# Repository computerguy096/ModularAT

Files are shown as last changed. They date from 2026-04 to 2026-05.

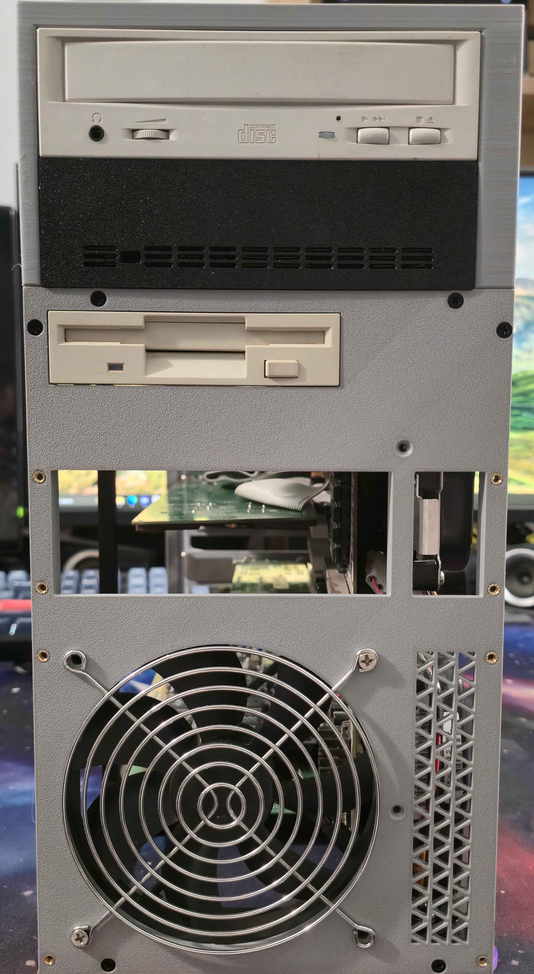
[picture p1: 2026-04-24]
images/front.jpg

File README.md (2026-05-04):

# ModularAT

A fully 3D printable computer case for Baby AT shaped motherboards, with new features the originals never had.

- modular design, can be assembled in a much smaller version
- compatible with all Baby AT motherboards (up to 330mm deep in the full configuration)
- customizable rear I/O area: supports motherboards with AT + PS/2 mouse combo, dual PS/2, etc
- 120mm intake fan: silent operation with plenty of airflow
- three hard drive mount points
- two 5.25 inch (half height, full length) drive bays
- one 3.5 inch drive bay for floppy drives
- ATX power supply support
- improved cable management, with dedicated space behind the motherboard tray for cables
- does not use those pesky plastic pegs!

The assembly instructions can be found at [this link](documentation/user_manual.pdf).

It is currently under development so it is possible some parts might not be finalized, print at your own risk.
main

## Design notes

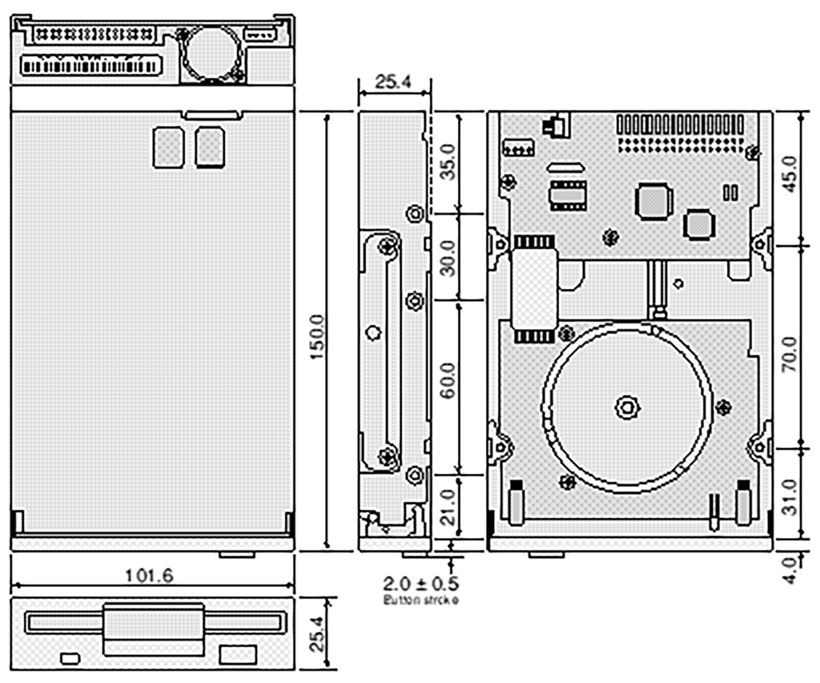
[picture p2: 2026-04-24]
documentation/floppy_spec.jpg

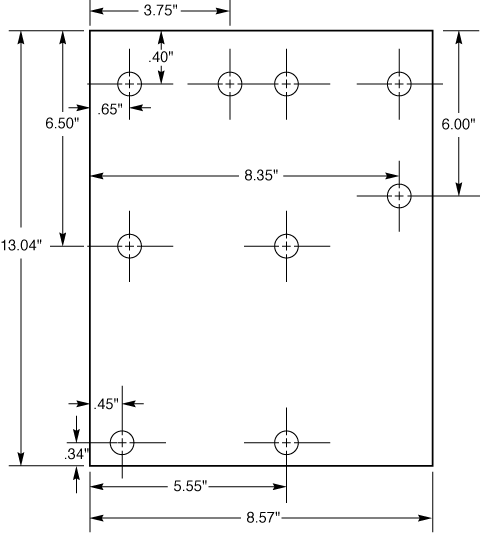
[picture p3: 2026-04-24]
documentation/babyAT_spec.gif

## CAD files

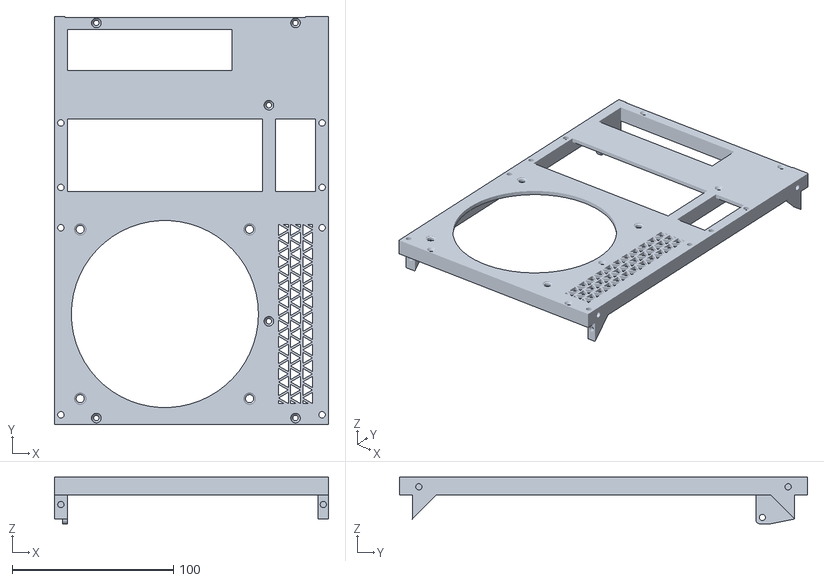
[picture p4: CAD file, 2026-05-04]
STL/frame/Front panel - main.stl
170.0 x 253.0 x 29.0

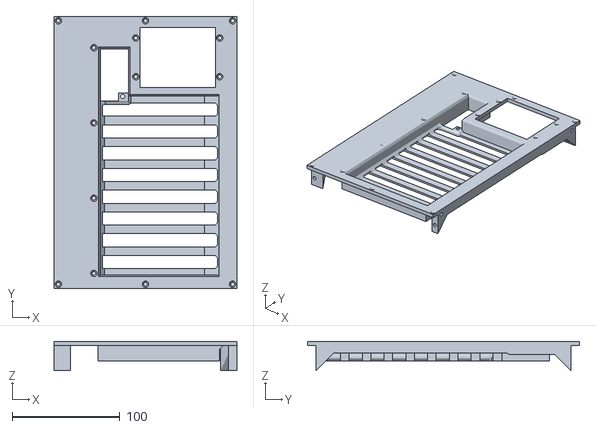
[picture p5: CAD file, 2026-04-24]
STL/frame/Rear panel - main.stl
170.0 x 253.0 x 27.1

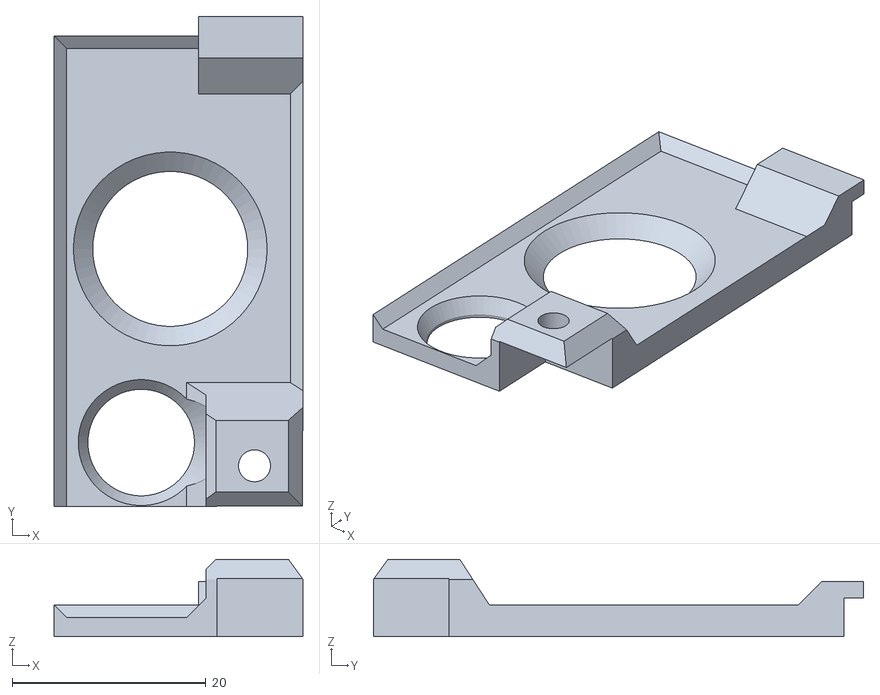
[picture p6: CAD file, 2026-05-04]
STL/accessories/KB cover - ATPS2.stl
25.7 x 50.6 x 8.00

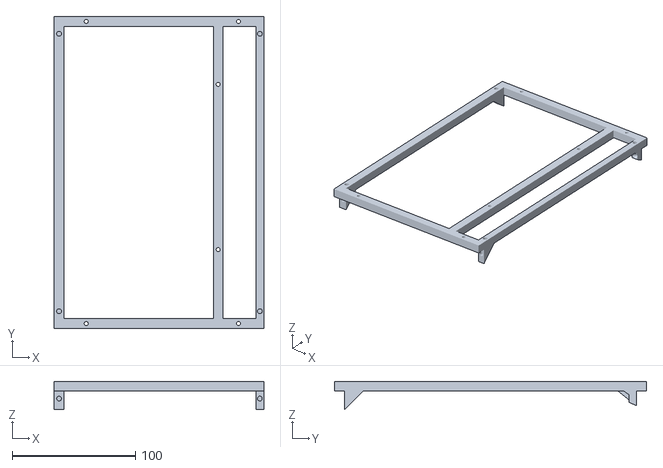
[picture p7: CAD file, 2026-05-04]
STL/frame/Stability frame.stl
170.0 x 253.0 x 23.0

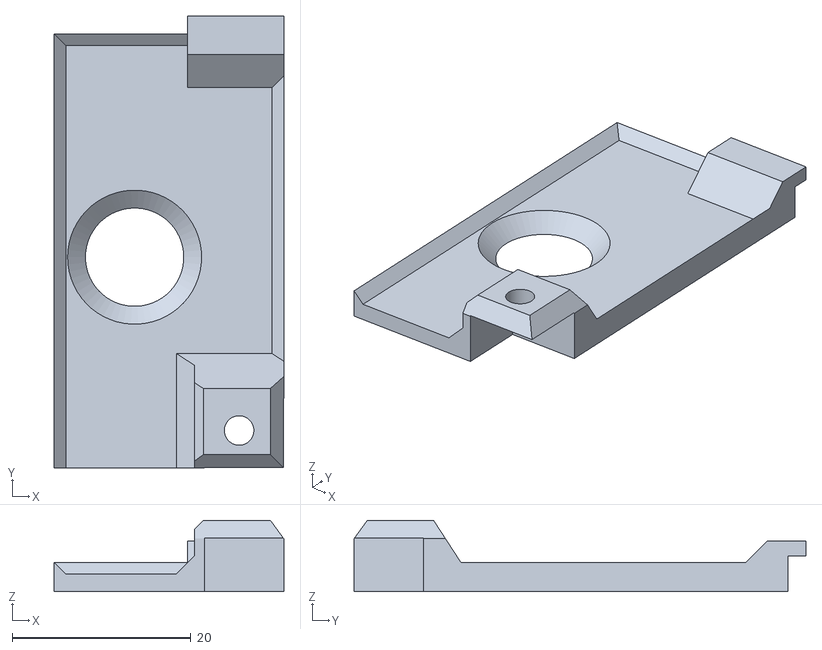
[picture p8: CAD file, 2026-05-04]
STL/accessories/KB cover - PS2.stl
25.7 x 50.6 x 8.00

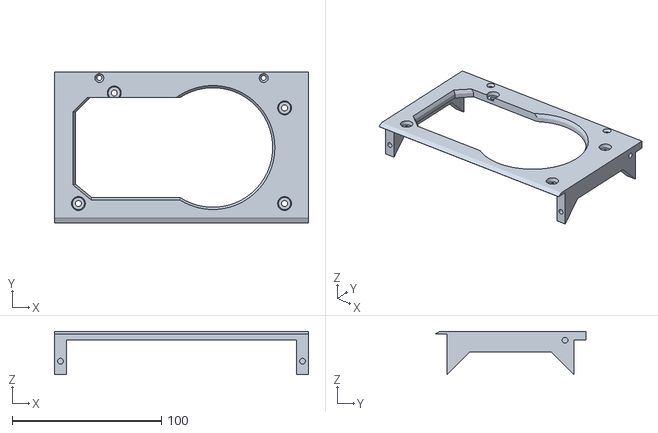
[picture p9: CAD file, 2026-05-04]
STL/frame/Rear panel - PSU plate.stl
170.0 x 101.0 x 29.1

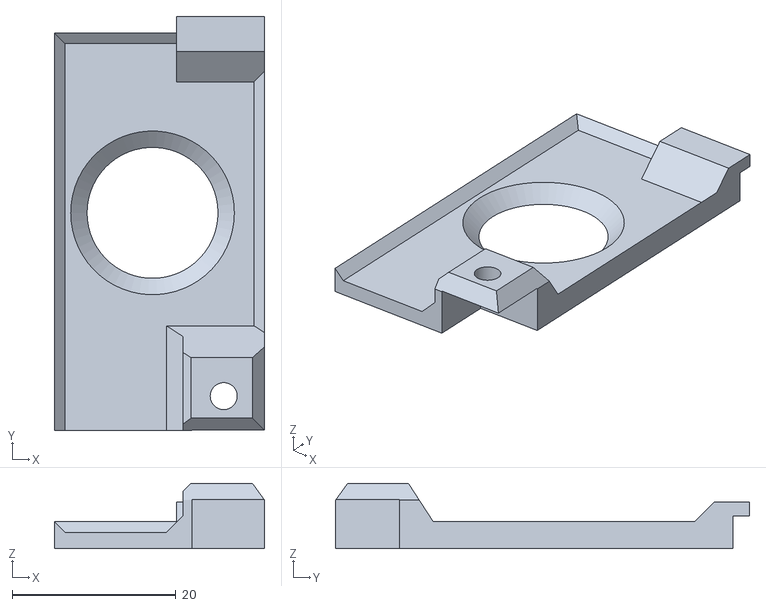
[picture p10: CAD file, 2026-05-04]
STL/accessories/KB cover- AT.stl
25.7 x 50.6 x 8.00

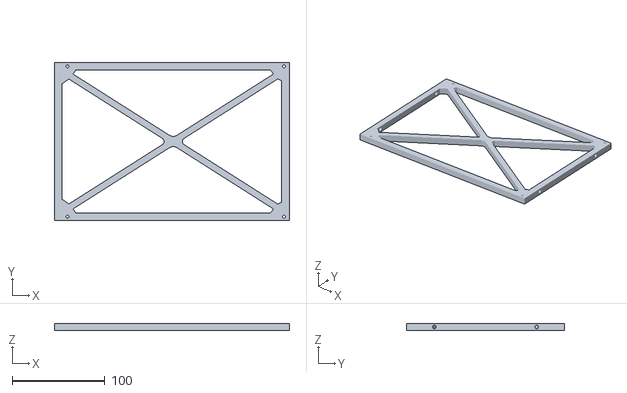
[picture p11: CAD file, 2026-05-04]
STL/frame/Top frame.stl
253.0 x 170.0 x 8.00

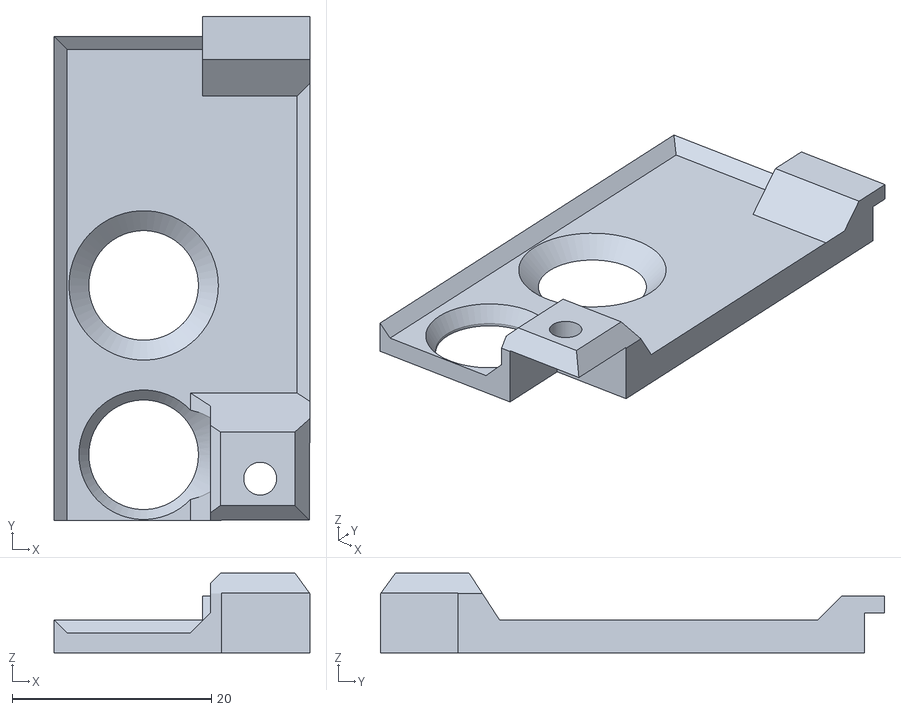
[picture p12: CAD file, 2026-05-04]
STL/accessories/KB cover - dual PS2.stl
25.7 x 50.6 x 8.00

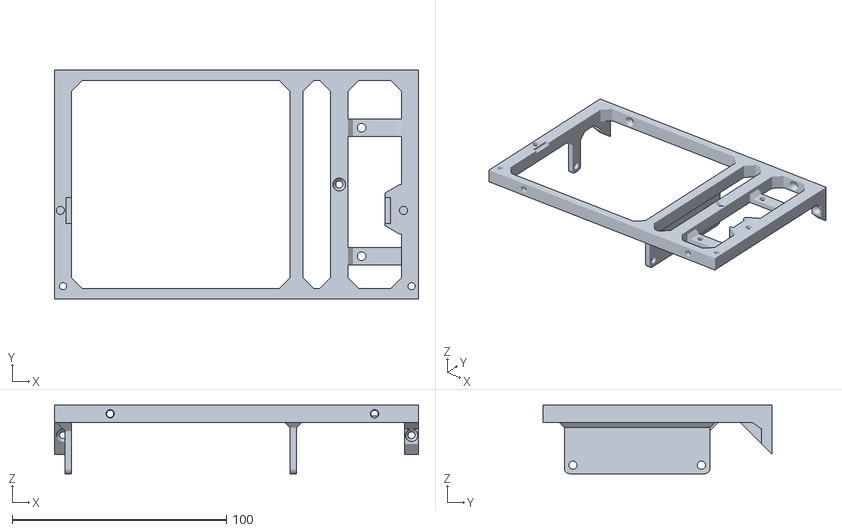
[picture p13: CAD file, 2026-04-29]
STL/frame/Middle extension frame.stl
170.0 x 107.0 x 32.0

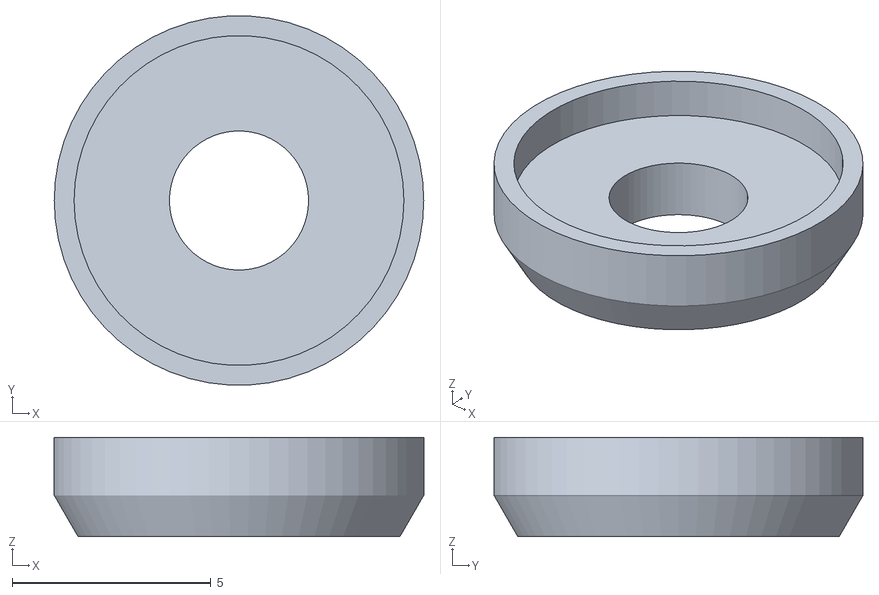
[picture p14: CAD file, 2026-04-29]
STL/accessories/Motherboard spacer.stl
9.30 x 9.29 x 2.50

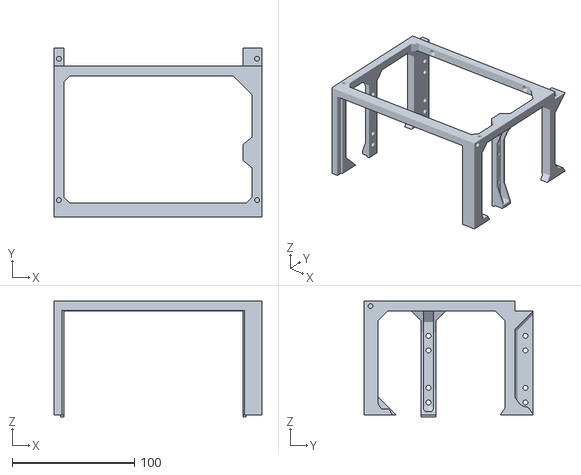
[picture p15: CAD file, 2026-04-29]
STL/frame/Top extension frame.stl
170.0 x 138.5 x 94.5

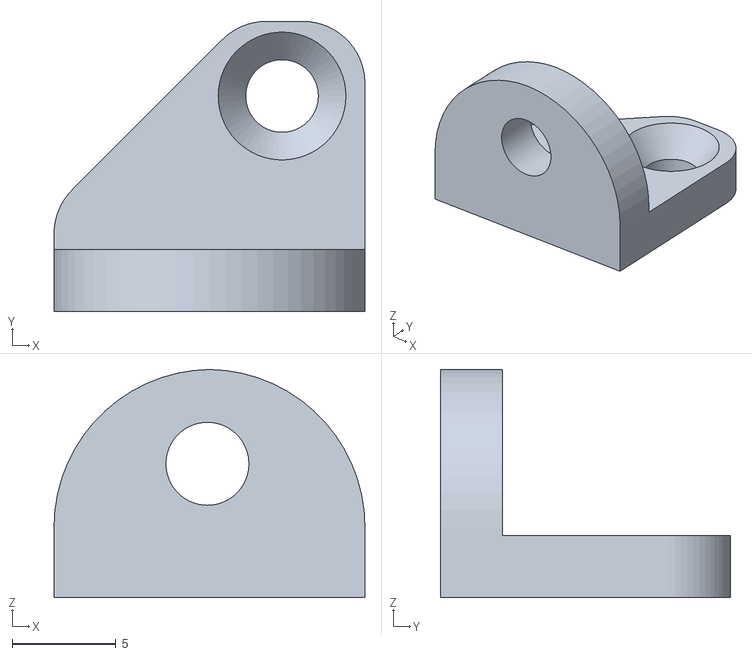
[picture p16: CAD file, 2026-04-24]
STL/accessories/HDD holder front upper.stl
15.0 x 14.0 x 11.0

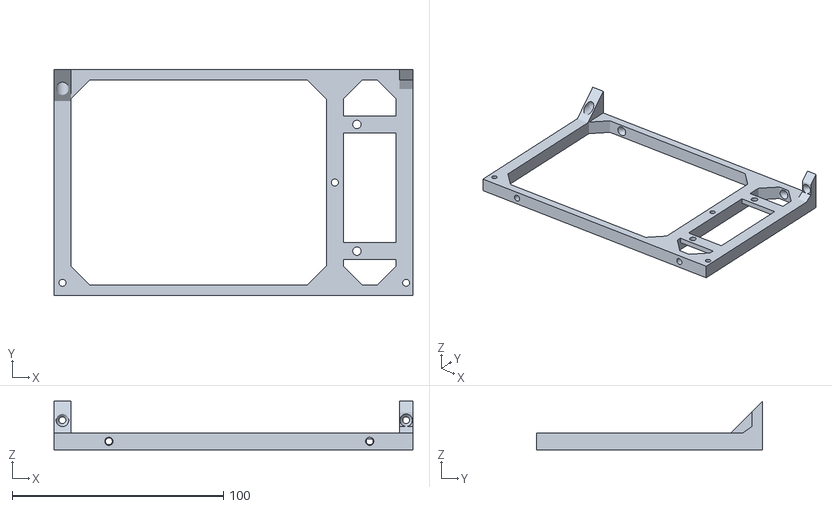
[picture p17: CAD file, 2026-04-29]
STL/frame/Bottom extension frame.stl
170.0 x 107.0 x 23.0

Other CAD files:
STL/accessories/KB cover - dual PS2 offset.stl
STL/accessories/HDD holder rear.stl
STL/frame/Bottom frame.stl
STL/accessories/HDD holder front lower.stl
STL/accessories/KB cover - blank.stl
STL/frame/Base extension frame.stl
STL/frame/Base frame.stl
STL/frame/Middle frame.stl

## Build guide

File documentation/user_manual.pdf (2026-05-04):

# ModularAT

## User’s guide

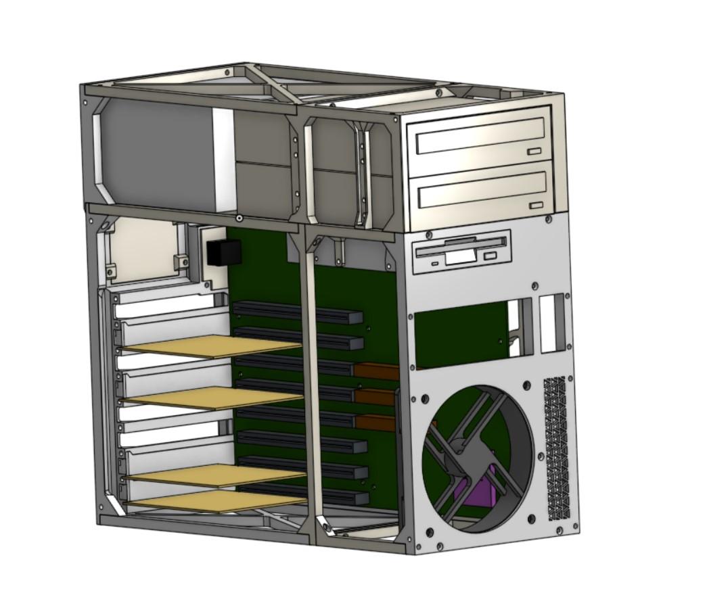
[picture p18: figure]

Revision 0.9-preliminary
May 4th, 2026

# Table of contents

A. Introduction | 3
1. What does this fit? | 3
2. Parts compatibility | 4
3. Brass inserts | 4
B. Bill of materials | 5
C. Getting started | 5
1. Base frame | 6
2. Rear frame | 7
3. Bottom frame | 8
4. Middle frame | 8
5. Stability frame | 9
6. Bottom extension frame | 10
7. Middle extension frame | 10
8. Base extension frame | 11
9. Front frame | 12
10. PSU frame | 13
11. Top frame | 13
12. Top extension frame | 14
D. Assembly | 15

## A. Introduction

This is a fully 3D printable computer case, which is designed to fit motherboards in the Baby AT form factor. One does not need to salvage other pre-defined sub assemblies from original cases, such as drive cages or motherboard trays, they are not required in the build process. All the essential structure parts are included in the repository.

### 1. What does this fit?

In a short answer, pretty much any Baby AT motherboard out there. Yes, even ones that have more than just a full size DIN plug for the keyboard, or which only have PS/2 ports. The case has a large opening at the back with a swappable plate, which allows for a flexible configuration, including a blank plate if the build is around an SBC + backplane. Most options out there are covered. Length wise, it can fit the maximum Baby AT size (up to 330mm) when using the frame extensions

An important factor to keep in mind is that the Baby AT form factor is not very well defined across the decade or so it was used throughout the late 80s and the first half of the 90s. Many motherboards from the 386 era (and older) have a tendency to not respect some of the hole positions when compared to most of the newer boards which followed them. As such, making a “one glove fits all hands” motherboard tray is very difficult to achieve without significantly increasing the build complexity. I have done measurements on my own board collection and discovered that the mounting holes can differ in position by as little as one millimeter!

Knowing all of this, I have decided the best approach is to stick to the most commonly used hole pattern, described in the Upgrading and Repairing PCs 10th Edition by Scott Mueller (great book by the way, I recommend giving it a glance over if you haven’t done so yet). It is inevitable some early boards will not match all the holes, but the motherboard spacers can be removed in case component legs exist in those spots.

### 2. Parts compatibility

The case can accommodate up to eight full height, full length expansion cards in its big configuration (they are screwed down using normal M3 PC screws). It can fit any standard ATX power supply (unusually long ATX units also fit, but they will eat space from the drive bay). Two 5.25 inch drive bays are provided, with support for long CD-ROMs or the typical 360K/1.2M floppy drives. Additionally, one 3.5 inch drive bay is provided underneath, for use with a typical 1.44M floppy drive (or any 3.5 inch bay drive accessory that uses floppy drive mounting holes). Up to three 3.5 inch hard drives can be mounted behind the motherboard tray. The reason for that number is simple: the 4th spot is reserved for PSU cable management, those cables have to go somewhere as well and it would be a shame to have them fill up the motherboard area, like most of the cases from that era.

### 3. Brass inserts

Initially, I designed the frame around conventional M3 hexagonal nuts that you can find in most hardware stores. This turned out to not be a great choice however, as it made the frame too thin in many places and prone to fracturing. In the next version, I used brass inserts which turned out to be way easier and stronger, without having to make the frame needlessly thick.

For ease of installation, a jig tool for brass inserts is recommended (though not required). The bare minimum you will need is an old soldering iron, for which you won’t care if the tip gets burnt up with plastic. In that case, I also recommend shaving the iron tip with a file or sandpaper so it can fit better inside the brass insert and make better contact with its surface.

A good technique I’ve seen online is to slowly melt it down in the part until you can just barely see part of the insert still exposed, but not fully seated in. Then you quickly come with a flat metallic object: knife, bigger bolt with a flattened head, or really, anything with a nice and flat surface which can press the insert the rest of the way down and make it flush with the surface of the part it gets embedded in. The end result will almost always be a perfectly flush brass insert.

## B. Bill of materials

You will need the following to build the frame:
- 1kg of PLA/PETG/ABS spool (or any material of choice)
- 97x M3 x 4.2mm (outer diameter) x 4mm (depth) brass inserts (105x w/ optional)
- 16x M3 x 6mm countersunk screws
- 19x M3 x 12mm countersunk screws
- 12x M3 x 16mm countersunk screws

It’s also good to have mounting hardware for the PC components:
- 4x 7/32” self tapping computer fan screws
- a handful of M3 motherboard screws
- a handful of #6-32 UNC (hard drive) screws

## C. Getting started

Have all the 3D models in the frame subdirectory printed and ready to use. From the accessories subdirectory you will need at least a few motherboard spacers.

For all the brass insert diagrams, arrows and/or circles will point to their destination. Arrows represent the direction from which the brass insert should be installed, while circles indicate the brass inserts should be inserted from the POV of the diagram (as seen). Pay attention to the colors of the markers and any remarks underneath the diagram, there can be special cases (mount from the other side, etc).

If a number is provided next to the marker, it represents the max depth of the hole in millimeters. This will be useful both for picking brass inserts with the right depth, as well as picking the screws with the right length for final assembly.

If a number is NOT provided next to the marker, it means the brass inserts and/or screws can be of any length, as long as they don’t run into other components you may install later (for e.g. the motherboard holes are see thru, but if there is a hard drive mounted on the backside, it could be damaged by screws which are too long in that area).

### 1. Base frame

Start with the base frame, by adding 24 inserts in the spots marked with red.

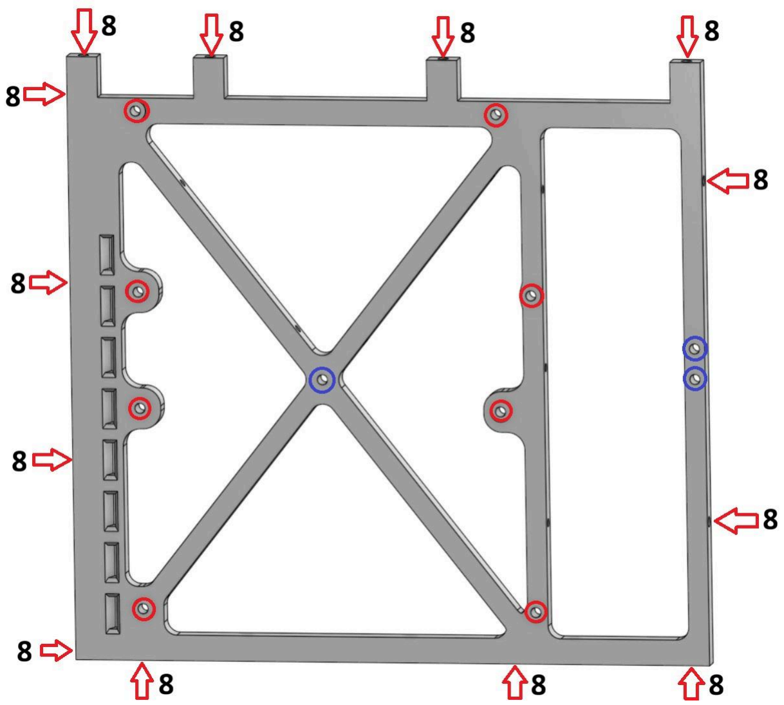
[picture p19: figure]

Turn the frame on the backside in order to add the three inserts marked in dark blue. They will be used for securing down the hard drives.

### 2. Rear frame

Next, add 15 inserts on the rear frame as shown. The green spots are optional, if you wish to have additional mounting points for the sidepanels. Flip it on the backside to install the blue spot.

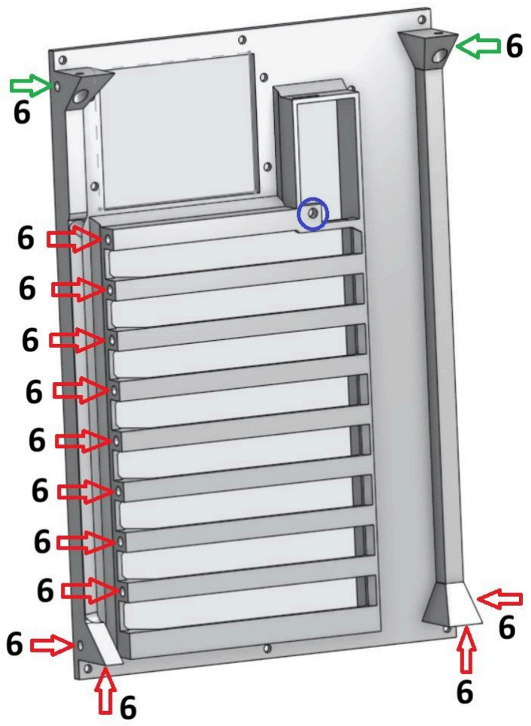
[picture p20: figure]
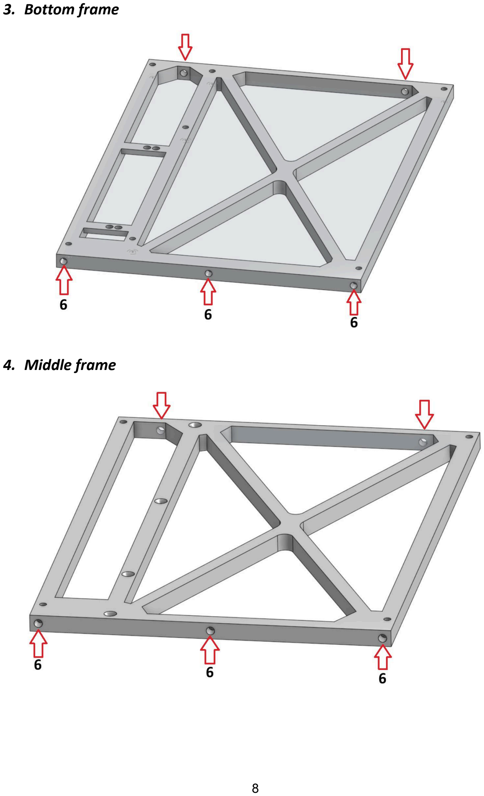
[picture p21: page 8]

### 3. Bottom frame

### 4. Middle frame

### 5. Stability frame

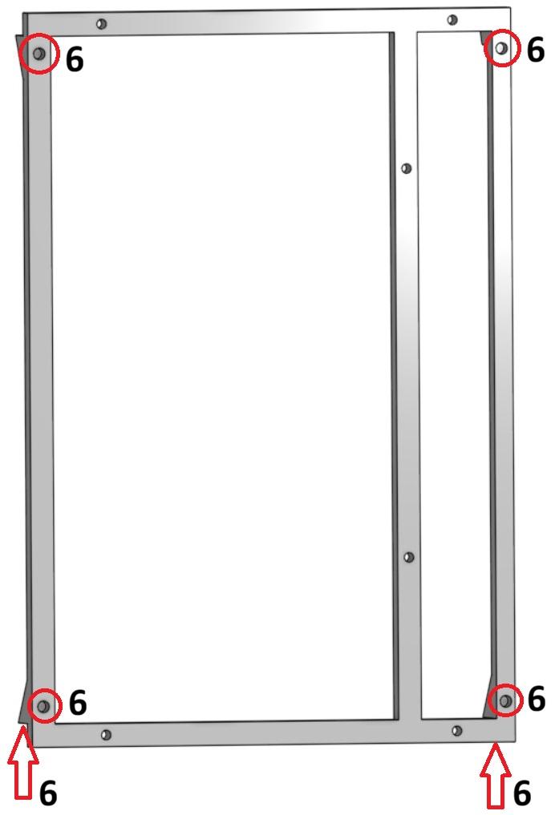
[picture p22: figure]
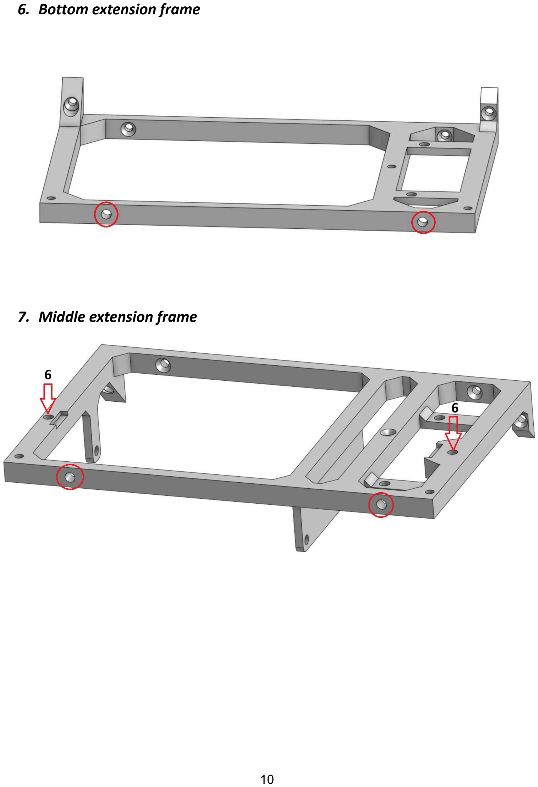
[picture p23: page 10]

### 6. Bottom extension frame

### 7. Middle extension frame

### 8. Base extension frame

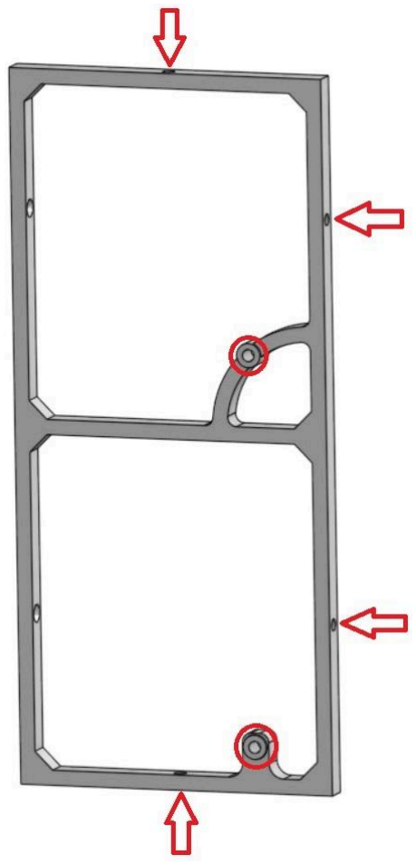
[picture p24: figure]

### 9. Front frame

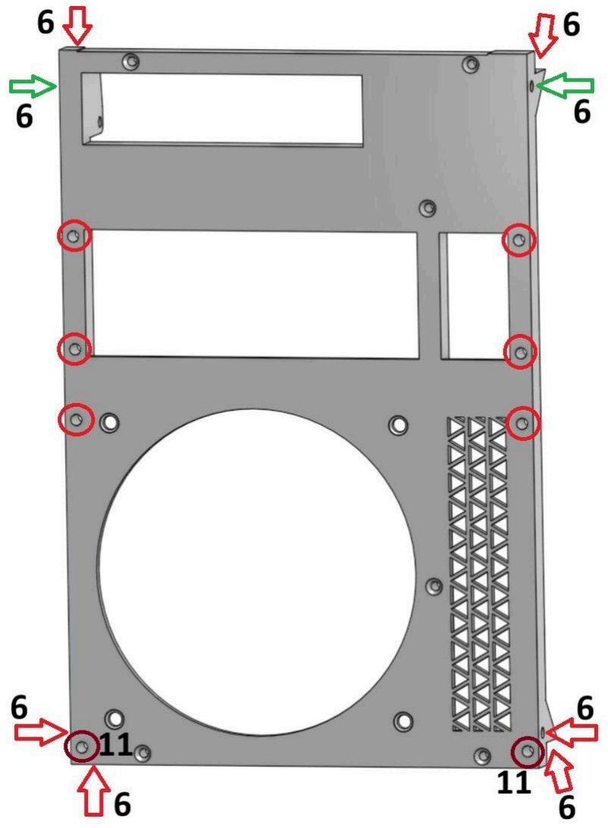
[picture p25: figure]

The dark red spots are see-through, but the max insert/screw depth should not exceed 11mm, otherwise it will collide with the rest of the frame. Green spots are optional.

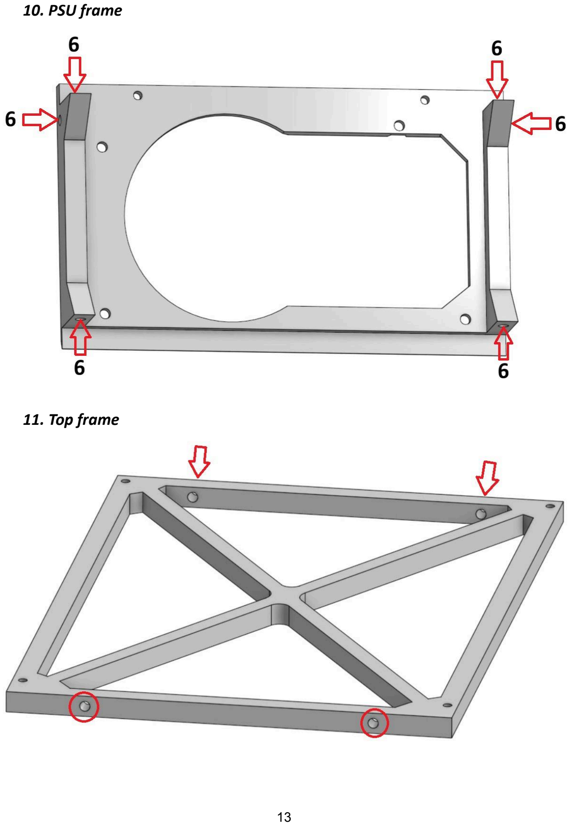
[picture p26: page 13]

### 10. PSU frame

### 11. Top frame

### 12. Top extension frame

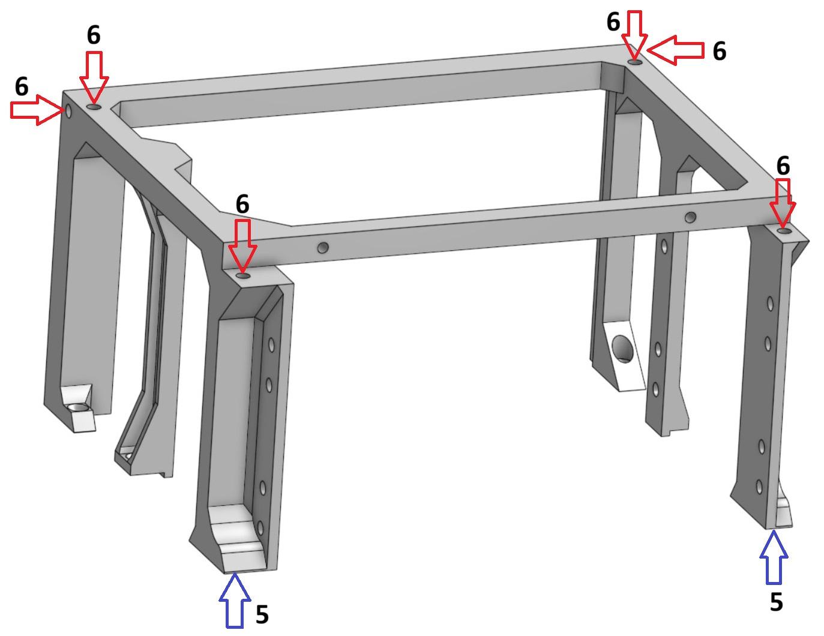
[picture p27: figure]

Due to physical constraints, the inserts on the bottom side can only go up to 5mm deep

## D. Assembly

All the frame parts have been prepared and are ready to be assembled together.

1. Start by joining the base and rear frames with 4x 6mm screws.

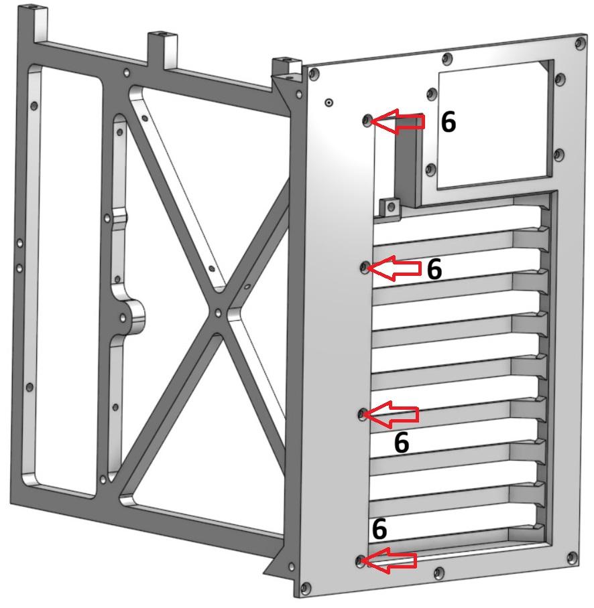
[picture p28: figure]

2. Then add the bottom frame with 3x 12mm and 3x 6mm screws.

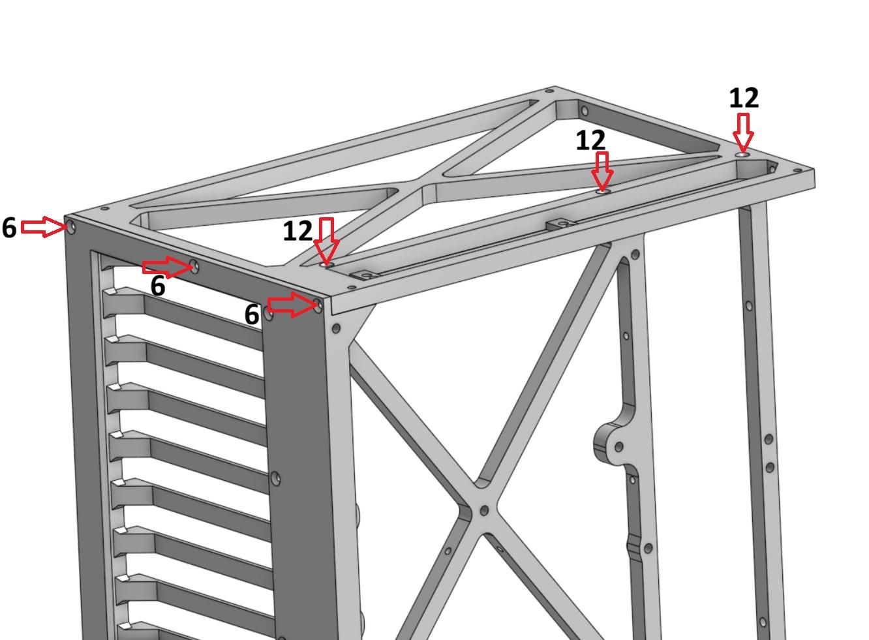
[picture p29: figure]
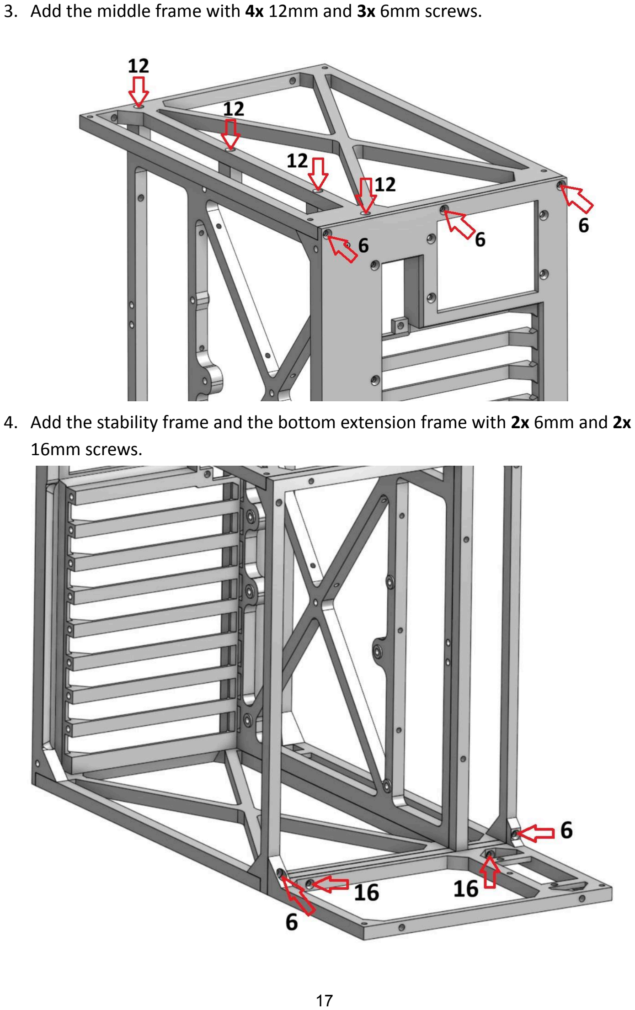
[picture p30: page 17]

3. Add the middle frame with 4x 12mm and 3x 6mm screws.
4. Add the stability frame and the bottom extension frame with 2x 6mm and 2x 16mm screws.

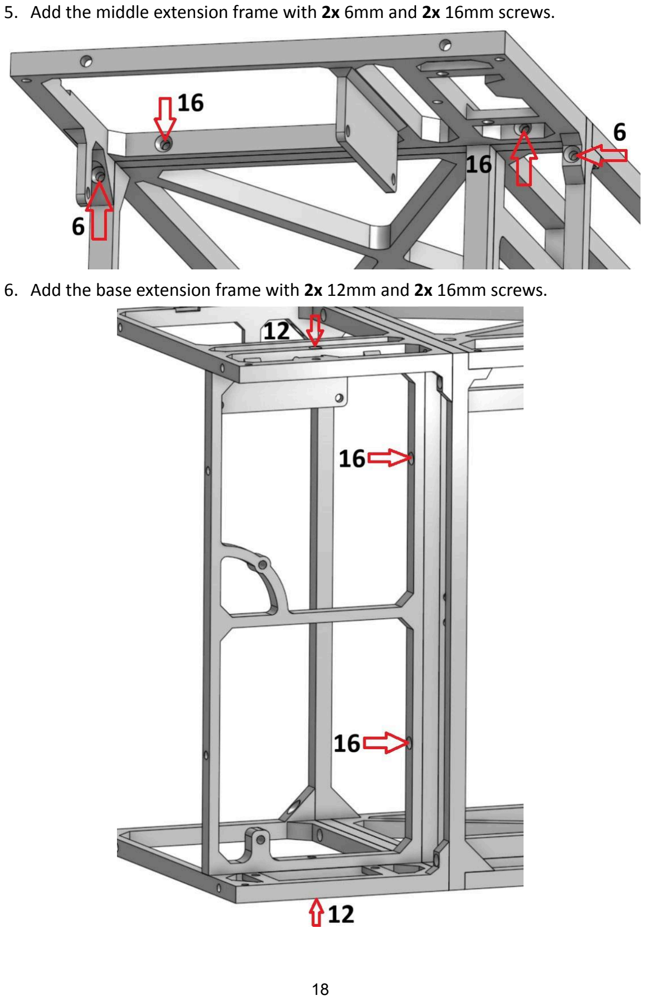
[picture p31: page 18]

5. Add the middle extension frame with 2x 6mm and 2x 16mm screws.
6. Add the base extension frame with 2x 12mm and 2x 16mm screws.

7. Add the front frame with 6x 12mm screws.

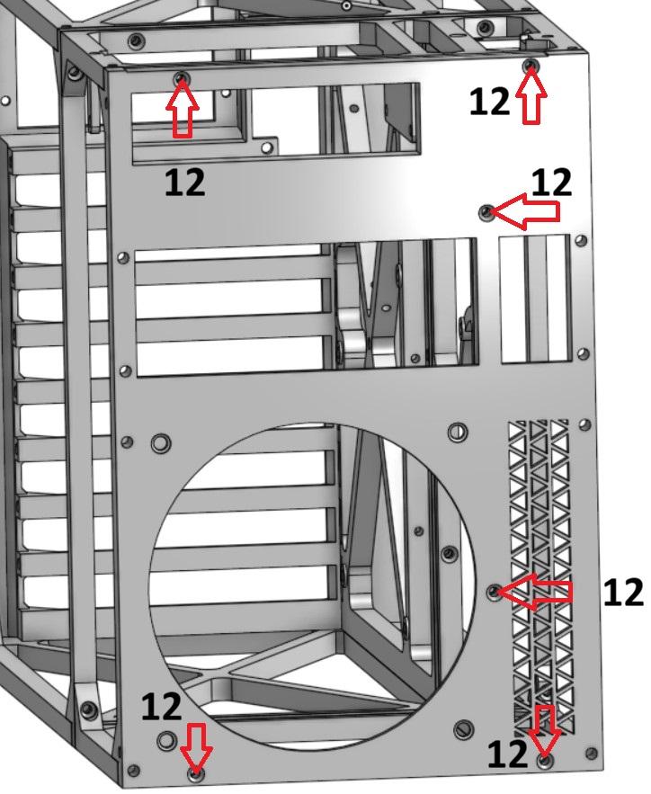
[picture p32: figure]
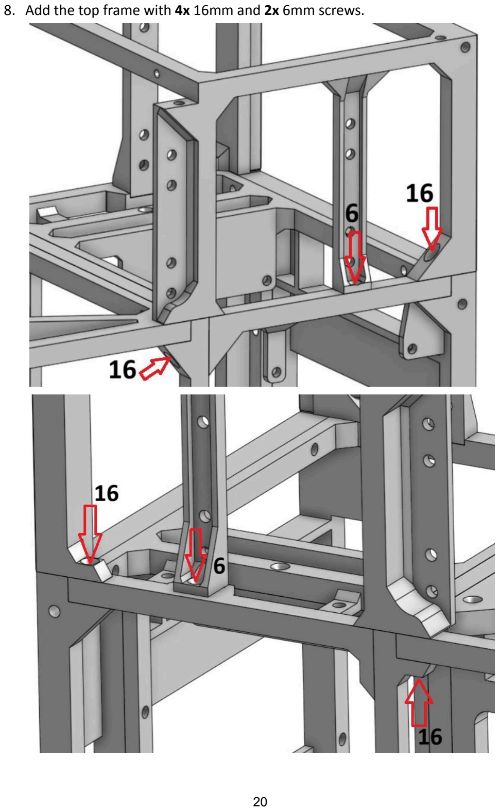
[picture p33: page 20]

8. Add the top frame with 4x 16mm and 2x 6mm screws.

9. Add the PSU frame with 2x 16mm screws.

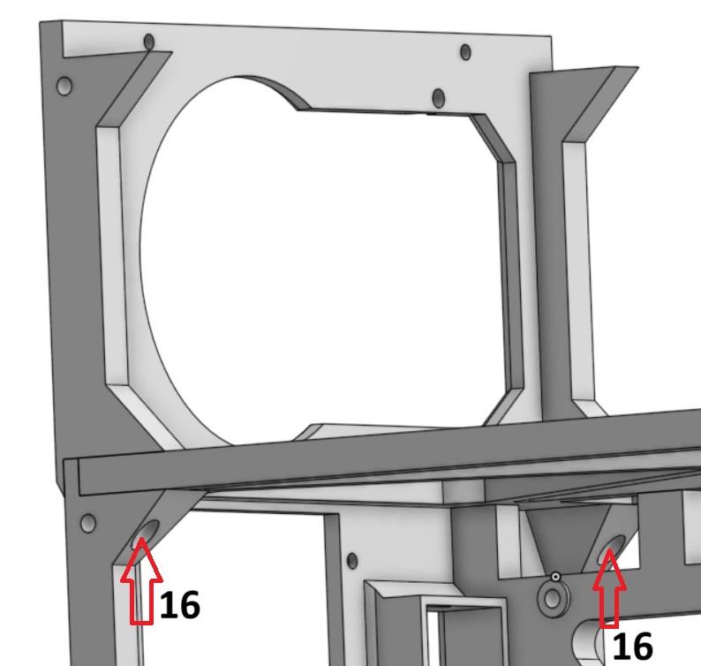
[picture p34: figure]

10. Add the top frame with 4x 12mm screws.

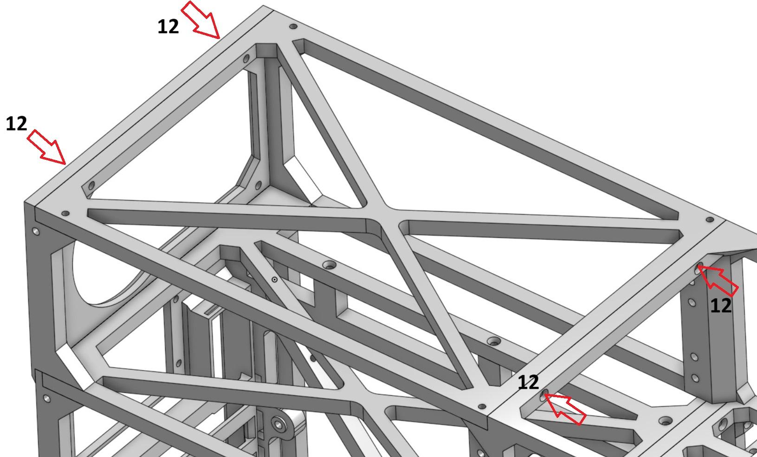
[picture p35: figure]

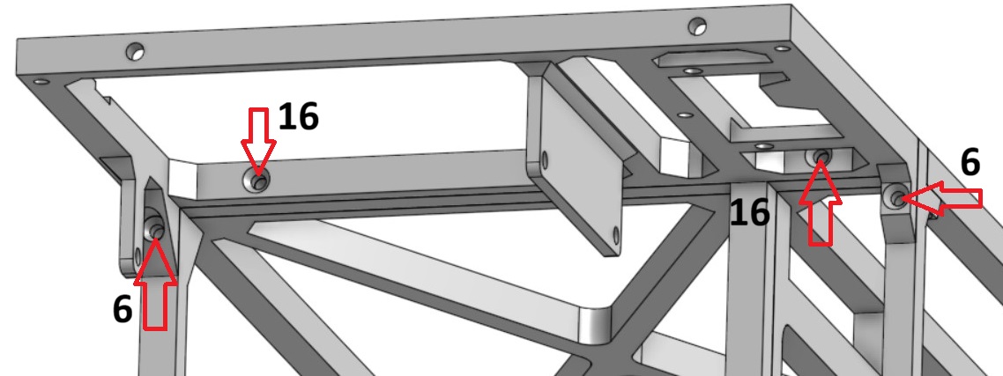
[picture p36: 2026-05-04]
documentation/diagrams/step5.jpg

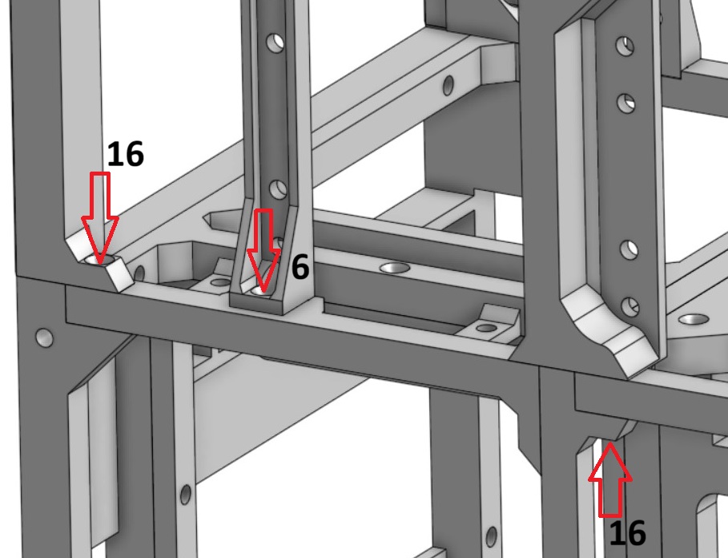
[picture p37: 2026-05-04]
documentation/diagrams/step8b.jpg

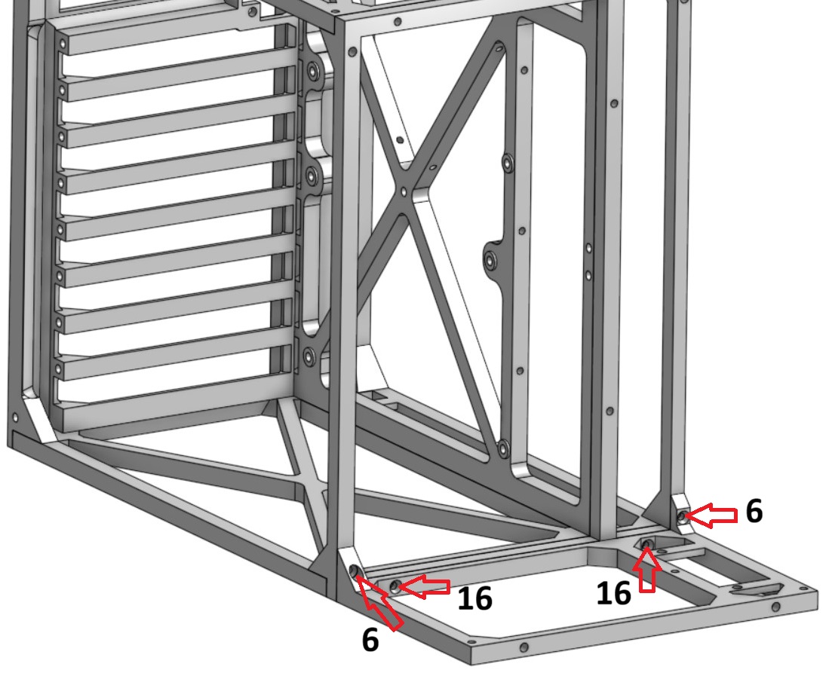
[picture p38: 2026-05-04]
documentation/diagrams/step4.jpg

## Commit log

2026-04-29 fixed bugs
    [Bottom extension frame.stl, Middle extension frame.stl, Motherboard spacer.stl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]
2026-05-04 added manual, fixed some parts
    [Front panel - main.stl, KB cover - 1 AT.stl, KB cover - ATPS2.stl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]
2026-05-04 user manual improvements
    [Stability frame.stl]
